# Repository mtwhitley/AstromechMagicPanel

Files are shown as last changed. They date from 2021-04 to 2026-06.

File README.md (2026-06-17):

# Astromech Magic Panel (AMP)

This project enables the building of LED Magic Panels for Astromech (R2-D2) droids. For more information on building your own droid, visit [Astromech.net](https://www.astromech.net)

## About
This version cycles through 8 predefined color pallets at 30 second intervals. The brightness pulses. The colors, intervals, sequences, speed, and density are all configurable. AMP requires 5v.

The default color sequence is:

 - Red, *\<Off\>*
 - Red with hints of Blue
 - Blue, *\<Off\>*
 - Red with hints of White
 - White, *\<Off\>* 
 - Blue with hints of White
 - Blue, *\<Off\>*
 - Rainbow, *\<Off\>*

The build is pretty straightforward but if you have any questions, send me a message in the [Astromech forums](https://astromech.net/forums/member.php?46338-umlungu). I can also be found on [Instagram](https://www.instagram.com/mw.labs/).

## Videos

Click each of the images below to view a video on Youtube of the animation.

Rainbow Animation

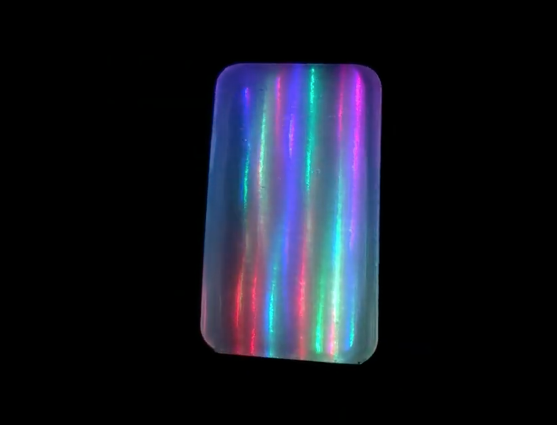
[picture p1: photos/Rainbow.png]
[](https://www.youtube.com/watch?v=29eVVwuxKLU)

Red and Blue Animations

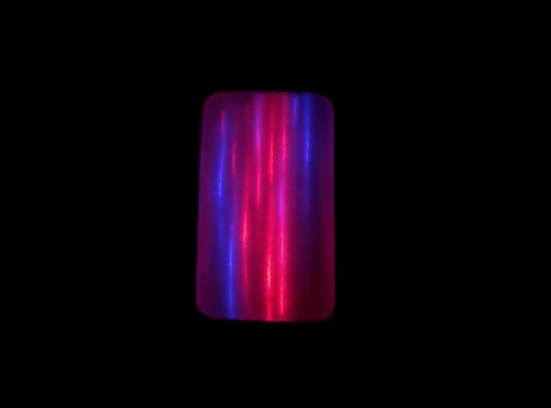
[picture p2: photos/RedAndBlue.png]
[](https://www.youtube.com/watch?v=H4pSufZo-co)

Horizontal & Vertical Lenses Compared

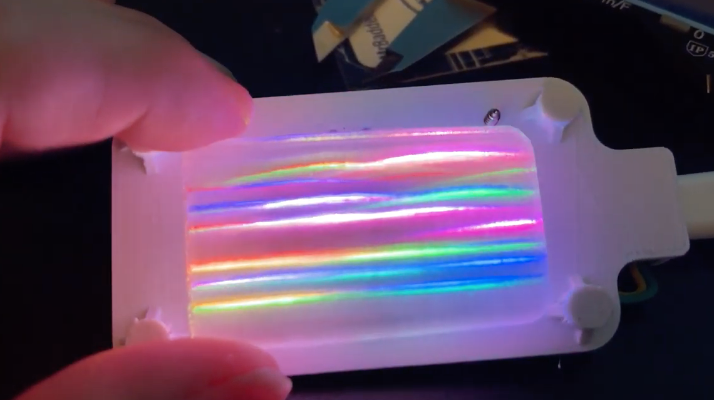
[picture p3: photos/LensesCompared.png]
[](https://www.youtube.com/watch?v=DCI3bl-R6VM)

## Getting Started

To build the Astromech Magic Panel (AMP) you will need the following hardware:

 - 1 x [Adafruit QT Py (SAMD21)](https://www.adafruit.com/product/4600)
 - 2 x [Adafruit DotStar 8x8 Grid](https://www.adafruit.com/product/3444) or [SparkFun LuMini LED Matrix - 8x8](https://www.sparkfun.com/products/15047) The Adafruit Matrix is more densely packed but the Sparkfun Matrix is easier to solder
 - 8 x M2, 6mm screws (Adafruit) or 8 x M3, 6mm screws (Sparkfun)
 - 8 x F/F jumper wires (Adafruit) or 4 x F/F jumper wires (Sparkfun)
 - USB Type-C Cable supporting both Data and Power 
 - Soldering Iron and Solder
 - The [Arduino IDE](https://www.arduino.cc/en/software)
 - The ability to print the included mounting brackets

Here are the components prior to assembly

**Sparkfun LuMini**

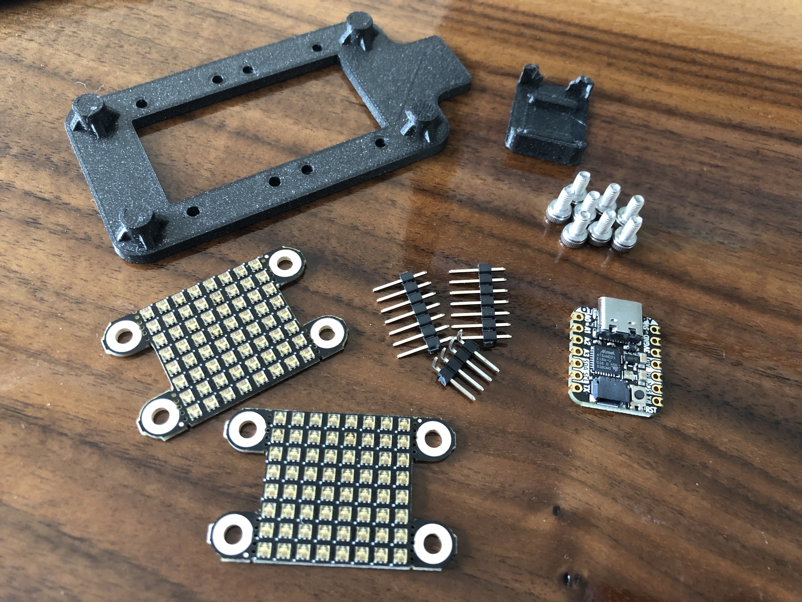
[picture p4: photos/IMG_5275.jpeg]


**Adafruit Dotstar**

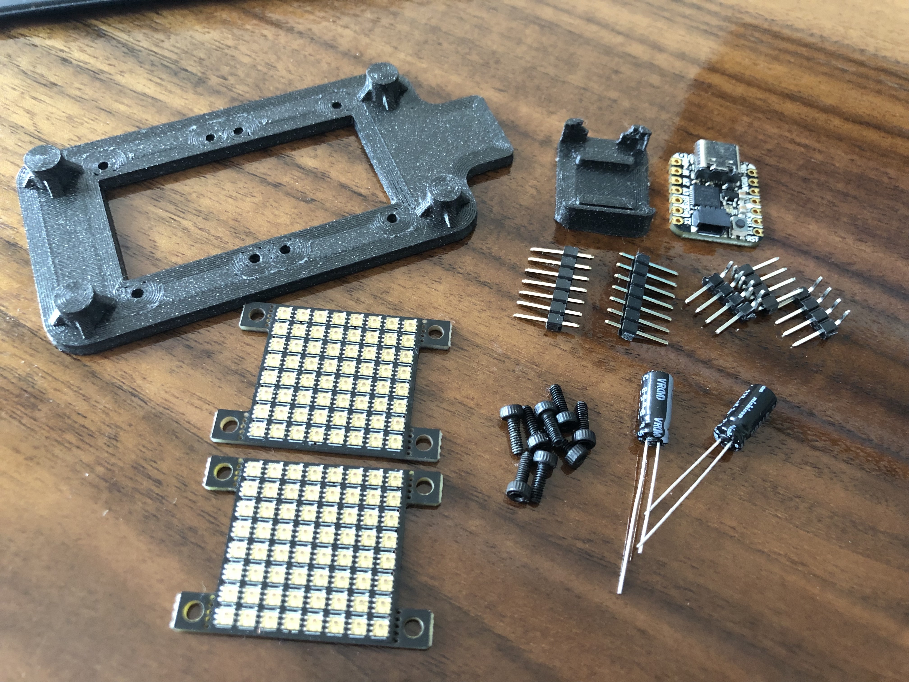
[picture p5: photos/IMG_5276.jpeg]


**Note:** You will also need a semi-transparent Magic Panel. If 3D printing this panel I recommend printing the panel *vertically* using a clear PETG filament. I used 6 perimeters/shells with 10% gyroid infill. Fewer perimeters and less infill will result in poorer LED diffusion. I highly recommend using [Michael Baddeley's](https://www.patreon.com/mrbaddeley/overview) excellent 3D printable models.

### Step 1: Solder 
First, solder the straight header pins to the Adafruit QT Py facing up.

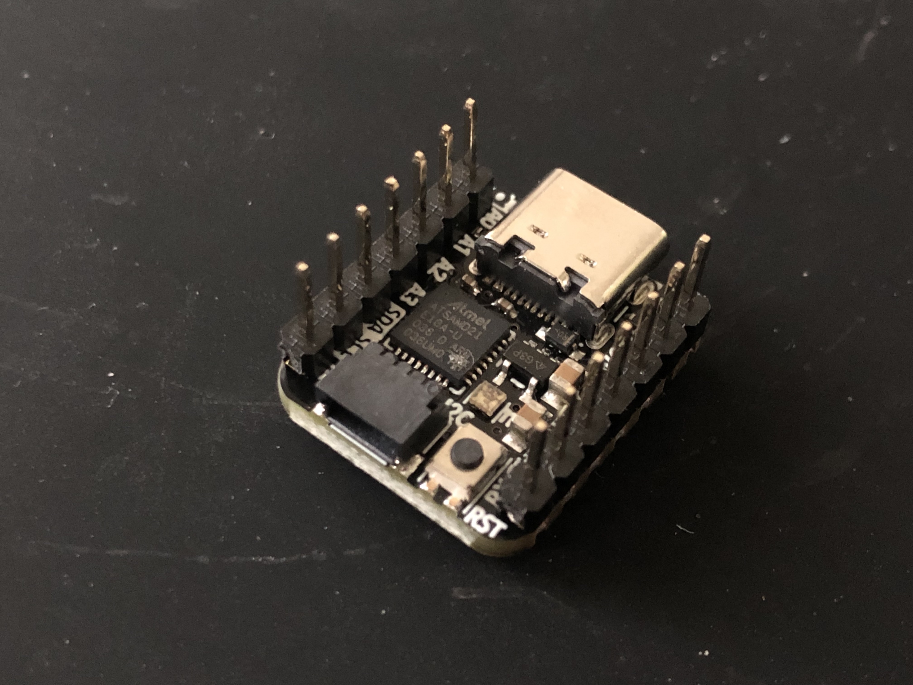
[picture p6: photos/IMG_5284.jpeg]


Next, solder two wires to the power pads on the opposite side of the QT Py.

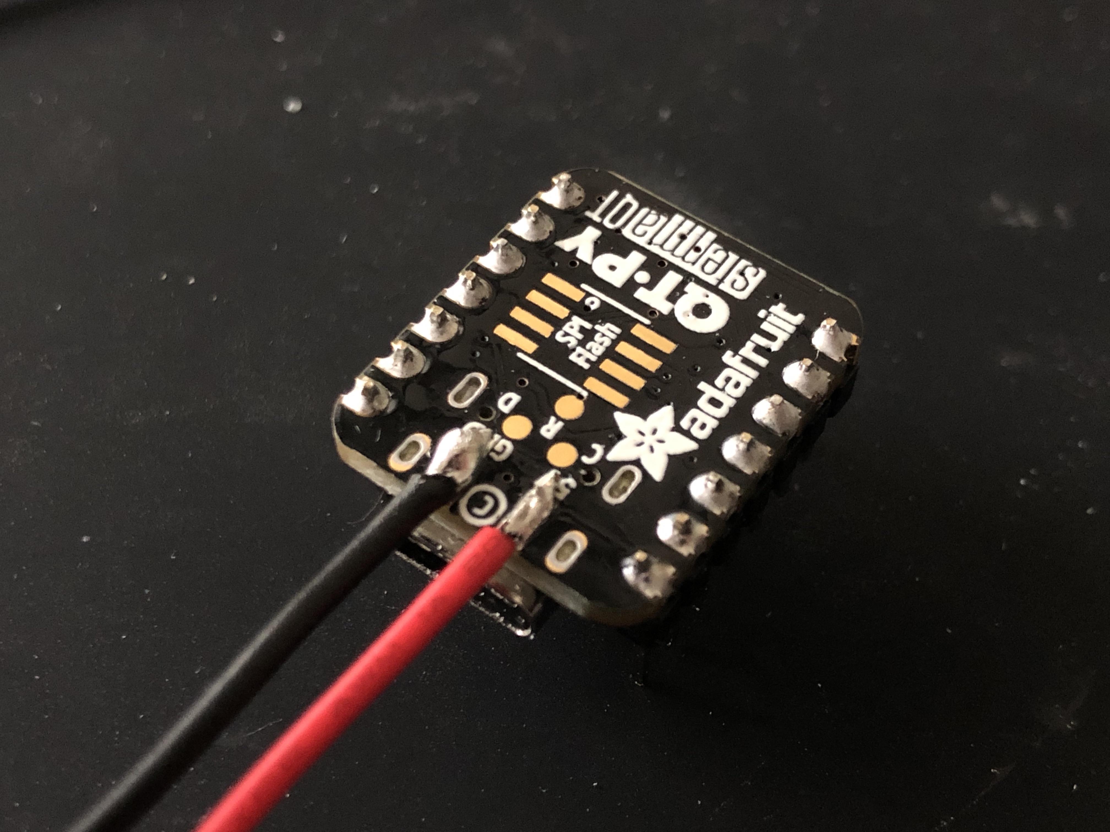
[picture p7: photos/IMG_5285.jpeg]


***Sparkfun Instructions***

Next, solder the 5V, CO-CI, DO-DI, and GND pads together on a flat surface. Also place a bit of solder on the remaining 5V, CI, DI, and GND pads on the top board.

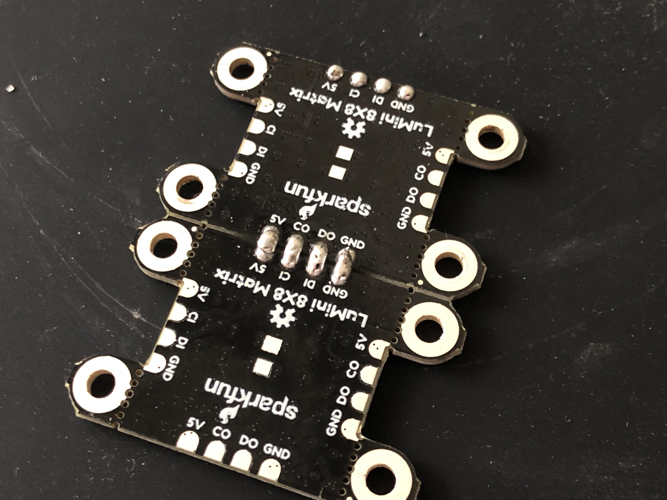
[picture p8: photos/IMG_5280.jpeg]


Next, spread the pins of the right angle headers apart slightly and solder them to the 5V, CI, DI, and GND pads on the top board.

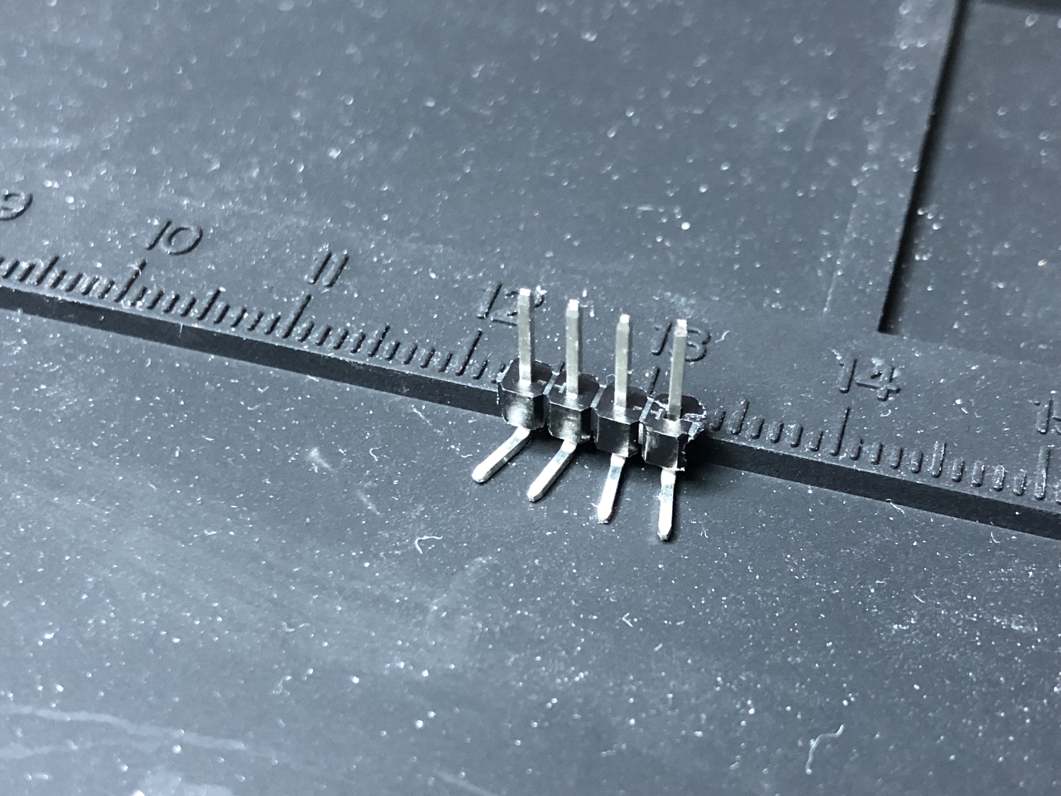
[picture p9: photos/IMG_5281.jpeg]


***Adafruit Instructions***

Next, solder the capacitors supplied with the matrices to the boards. Be sure to solder the + and - capacitor leads to the corresponding pads on the board. Once soldered trim the leads. Also place a bit of solder on the CIN, DIN, GND, and +5V pads. Do the same for the +5V, GND, DOUT, and COUT pads on one of the boards.

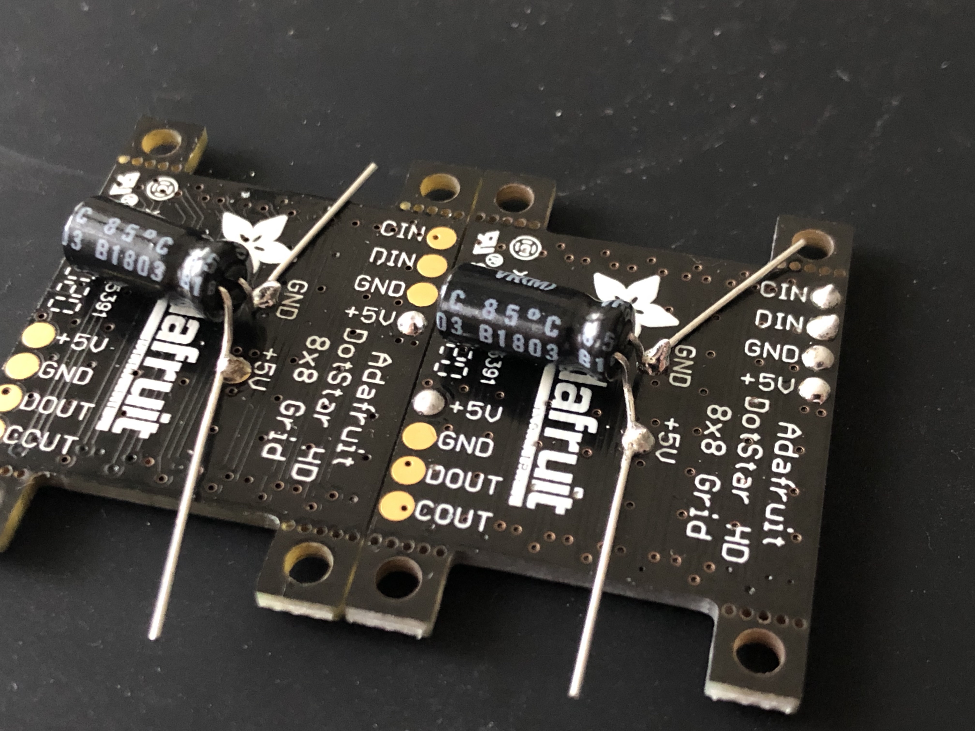
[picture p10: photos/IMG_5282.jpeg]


Next, solder the right angle headers to the pads prepared in the step above. Note that with the Adafruit board the right angle headers do not need to be spread apart.

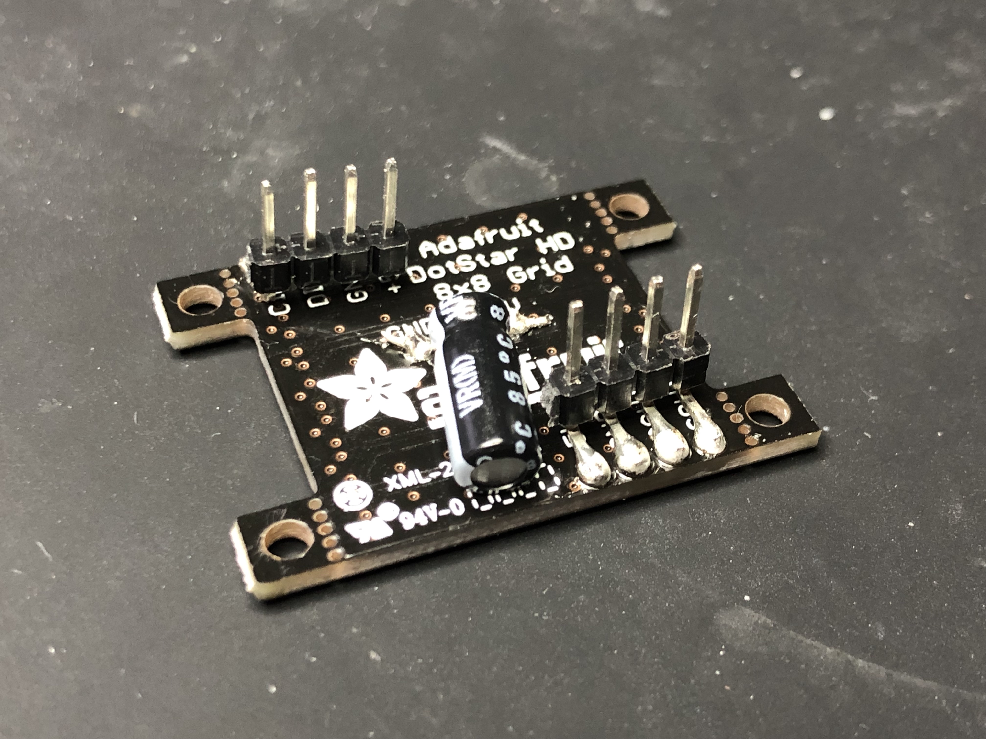
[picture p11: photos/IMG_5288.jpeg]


### Step 2: Program
Using a USB C cable, a computer, and the [Arduino IDE](https://www.arduino.cc/en/software), connect the QT Py microcontroller and upload the *AstromechMagicPanel.ino* sketch found in the *src* directory.

### Step 3: Print
3D print the QT Py and Base mounting brackets found in the models folder. Only print the base model corresponding to the LED matrix you are using.

Print the Magic Panel *vertically* (standing on the shorter side) using clear PETG filament. I used 6 perimeters/shells with 10% gyroid infill. Fewer perimeters and less infill will result in poorer LED diffusion. I recommend using "Panel 7" model from [Michael Baddeley's](https://www.patreon.com/mrbaddeley/overview) project.  The light is diffused perpendicular to the print layer direction.

### Step 4: Assemble
Next, use CA glue to attach the QT Py bracket to the base.

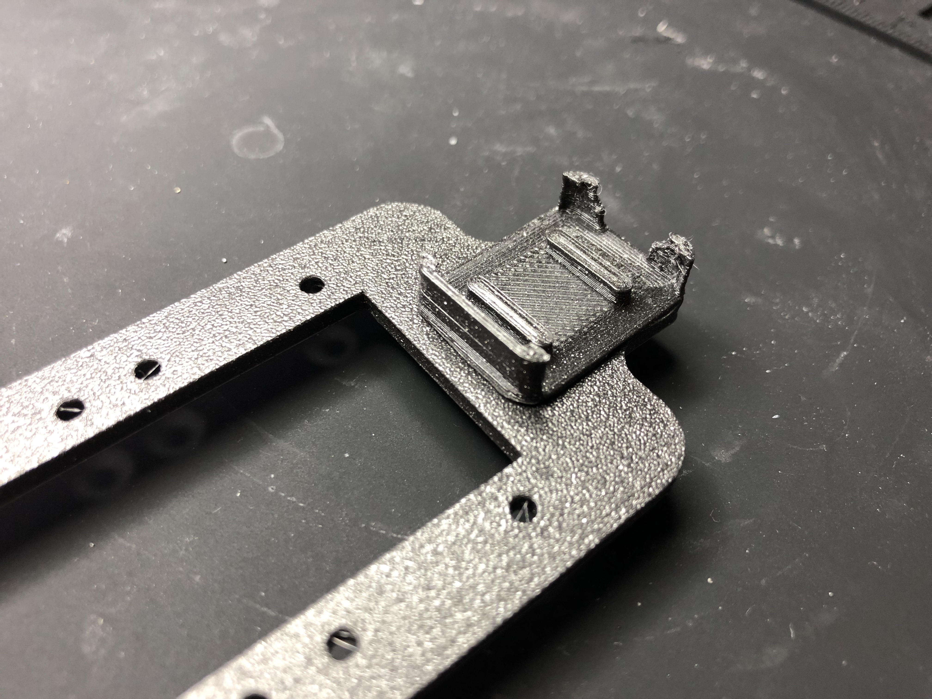
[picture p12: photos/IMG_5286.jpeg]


Next, screw the LED panels into the bracket.

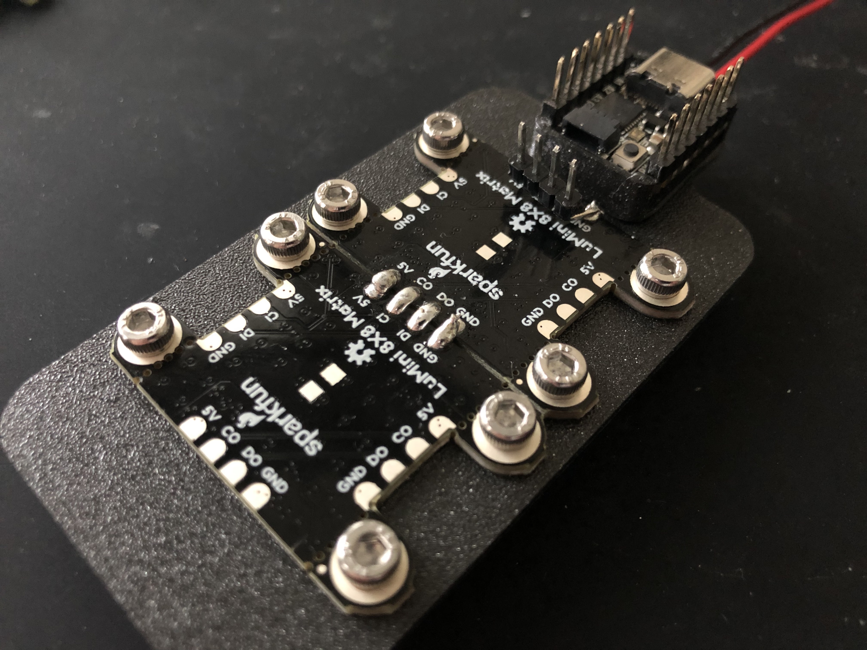
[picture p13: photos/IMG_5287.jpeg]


Then connect the QT Py to the LED panels using the female jumper wires. If using the Sparkfun Lumini, connect CI to pin 0 and DI to pin 1. If using Adafruit Dotstar, connect CIN to pin 0 and DIN to pin 1. Don't forget to connect the 5V and GND pins as well. 

**Assembled Sparkfun LuMini AMP**

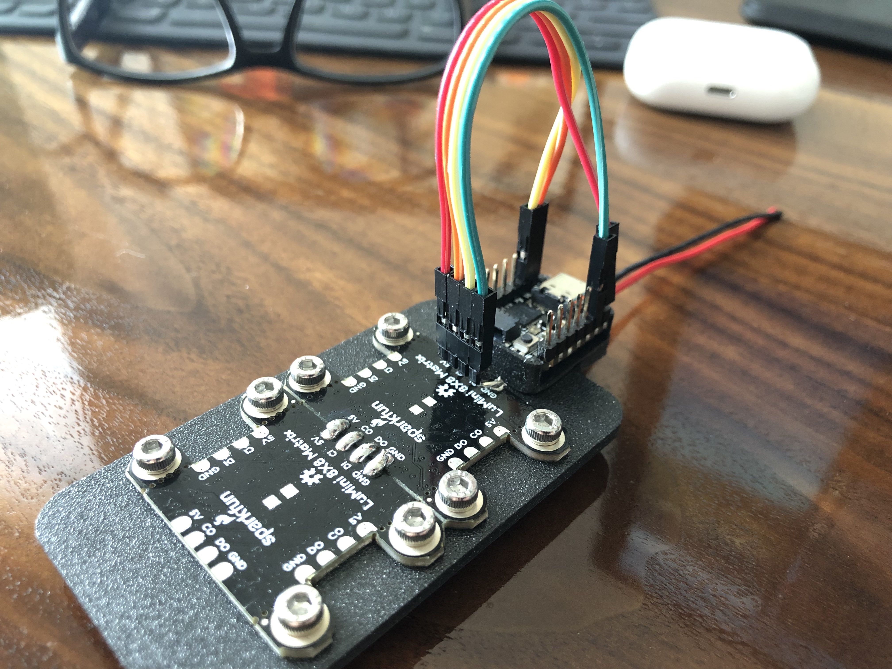
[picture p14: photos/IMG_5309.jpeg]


**Assembled Adafruit Dotstar AMP**

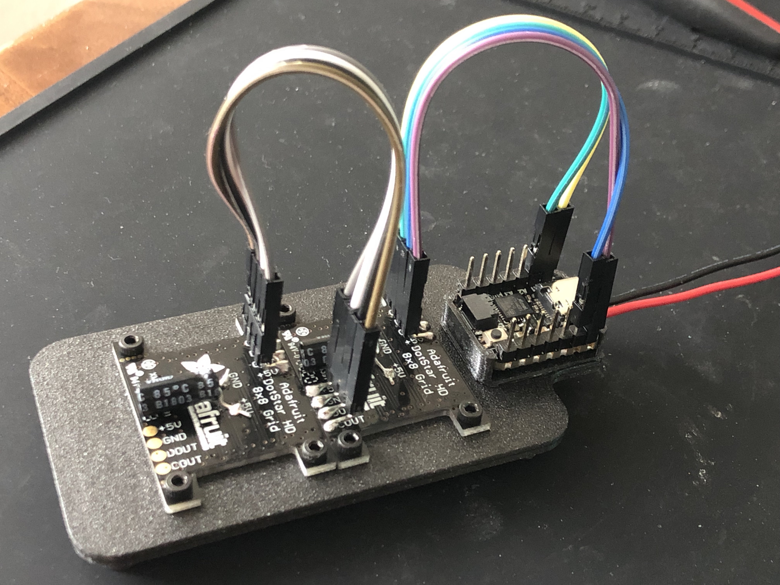
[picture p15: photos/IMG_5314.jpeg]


Once assembled, AMP can be installed into the dome directly over the semi-transparent Magic Panel and connected to a 5v power supply.

## More Help
For additional assistance please contact Michael Whitley (umlungu) on the Astromech.net forums.

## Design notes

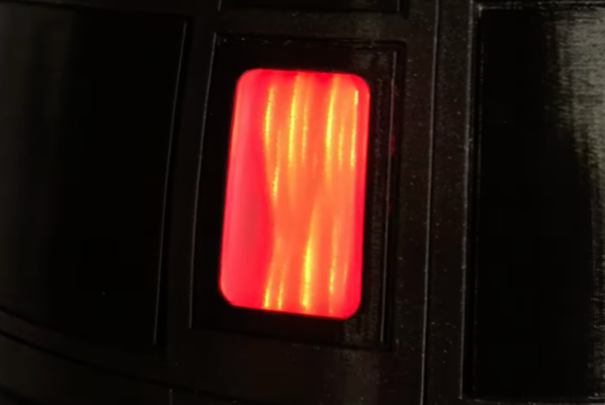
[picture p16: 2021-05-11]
photos/Red.png

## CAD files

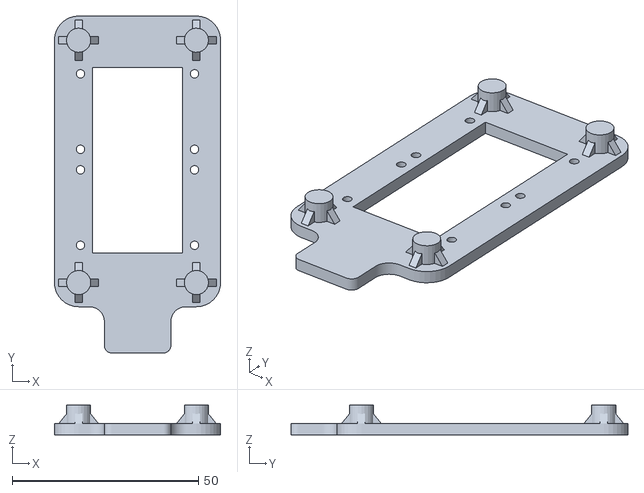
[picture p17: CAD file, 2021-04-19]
models/AstromechMagicPanel_Base-Adafruit.stl
44.6 x 90.4 x 8.00

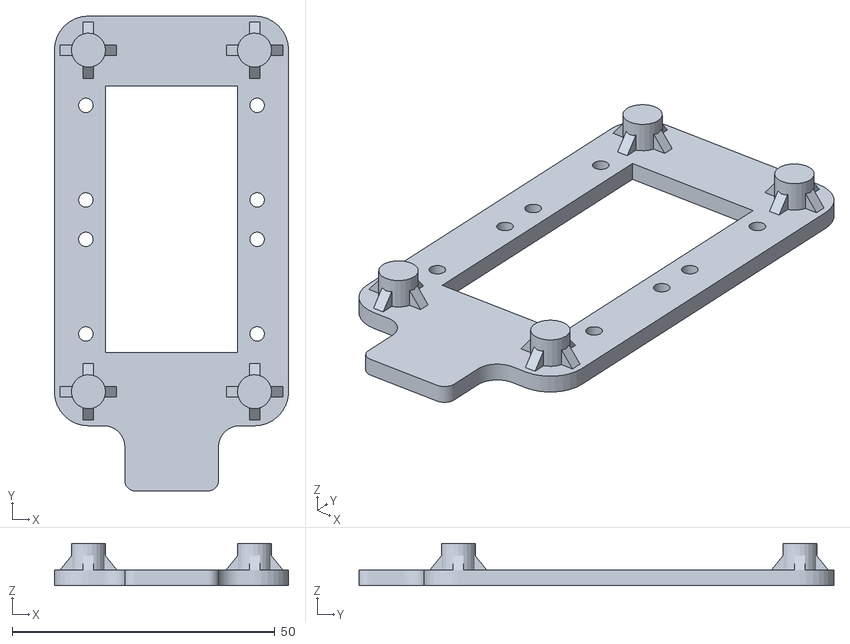
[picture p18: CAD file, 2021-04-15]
models/AstromechMagicPanel_Base-Sparkfun.stl
44.6 x 90.4 x 8.00

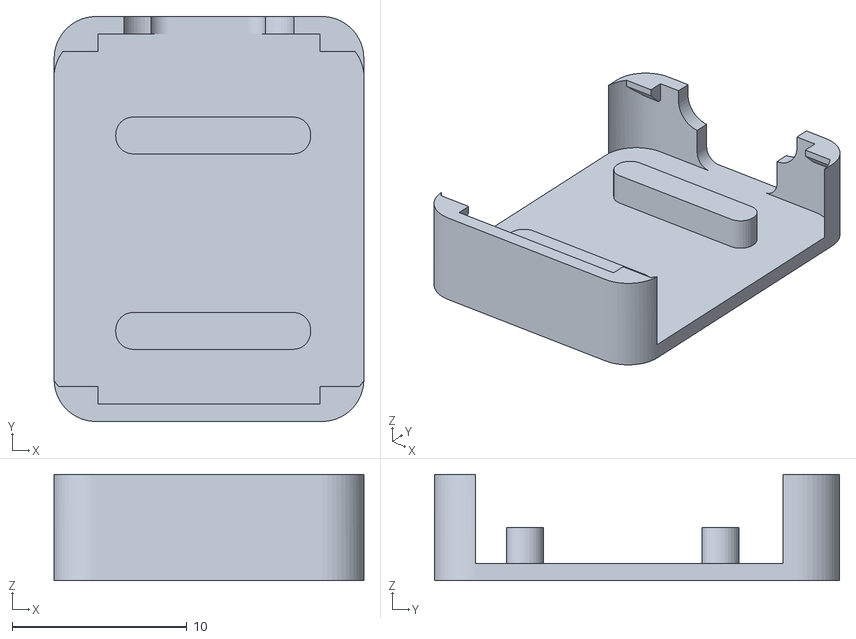
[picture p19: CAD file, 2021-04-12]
models/AstromechMagicPanel_QTPy.stl
17.7 x 23.2 x 6.10

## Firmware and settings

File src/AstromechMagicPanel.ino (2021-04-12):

#include "FastLED.h"

// =======================================================================================
//  Astromech Magic Panel (AMP)
// =======================================================================================
//                                 
// This code animates the Magic Panel for Astromech droids. When combined with a semi-
// transparent panel and LEDs it produces a striking effect. This code is based on 
// FastLED's TwinkleFox example http://fastled.io
//
// Homepage: https://github.com/mtwhitley/AstromechMagicPanel
// 
// Authors: Michael Whitley (astromech.net - umlungu), Mark Kriegsman (FastLED)
//
// Required Library: 
//   FastLED
//
// Setup: Use with 2 x APA102 20/20 8x8 matrix panels from Adafruit or Sparkfun. 
// I recommend using an Adafruit QT Py to drive the LEDs, but any 
// microcontroller 16MHz or faster will likely work. If using a different board
// be sure to adjust the Data and Clock pins accordingly.
//
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
#define DATA_PIN 1          // Adafruit QT Py
#define CLK_PIN  0          // Adafruit QT Py
#define LED_TYPE    APA102  // APA102 20/20 8x8 matrix panels 
#define COLOR_ORDER BGR     // APA102 20/20 8x8 matrix panels 
#define NUM_LEDS    128     // 2 x APA102 20/20 8x8 matrix panels 
#define BRIGHTNESS  25      // The LED panels can get HOT so don't go above 25-30 max

// Overall twinkle speed.
// 0 (VERY slow) to 8 (VERY fast).  
// Default is 4.
int twinkle_speed=4;

// Overall twinkle density.
// 0 (NONE lit) to 8 (ALL lit at once).  
// Default is 2.
int twinkle_density=2;

// How often to change color palettes.
#define SECONDS_PER_PALETTE  30

// =======================================================================================
//  Color Pallete Definitions - Use "CRGB::Gray" for white to keep the brightness uniform
// =======================================================================================

const TProgmemRGBPalette16 White_p FL_PROGMEM =
{  CRGB::Gray,  CRGB::Gray,  CRGB::Gray,  CRGB::Gray,
   CRGB::Gray,  CRGB::Gray,  CRGB::Gray,  CRGB::Gray,
   CRGB::Gray,  CRGB::Gray,  CRGB::Gray,  CRGB::Gray,
   CRGB::Gray,  CRGB::Gray,  CRGB::Gray,  CRGB::Gray};

const TProgmemRGBPalette16 Red_p FL_PROGMEM =
{  CRGB::Red,  CRGB::Red,  CRGB::Red,  CRGB::Red,
   CRGB::Red,  CRGB::Red,  CRGB::Red,  CRGB::Red,
   CRGB::Red,  CRGB::Red,  CRGB::Red,  CRGB::Red,
   CRGB::Red,  CRGB::Red,  CRGB::Red,  CRGB::Red};

const TProgmemRGBPalette16 Blue_p FL_PROGMEM =
{  CRGB::Blue,  CRGB::Blue,  CRGB::Blue,  CRGB::Blue,
   CRGB::Blue,  CRGB::Blue,  CRGB::Blue,  CRGB::Blue,
   CRGB::Blue,  CRGB::Blue,  CRGB::Blue,  CRGB::Blue,
   CRGB::Blue,  CRGB::Blue,  CRGB::Blue,  CRGB::Blue};

const TProgmemRGBPalette16 Black_p FL_PROGMEM =
{  CRGB::Black,  CRGB::Black,  CRGB::Black,  CRGB::Black,
   CRGB::Black,  CRGB::Black,  CRGB::Black,  CRGB::Black,
   CRGB::Black,  CRGB::Black,  CRGB::Black,  CRGB::Black,
   CRGB::Black,  CRGB::Black,  CRGB::Black,  CRGB::Black};

const TProgmemRGBPalette16 RedWhite_p FL_PROGMEM =
{  CRGB::Red,  CRGB::Red,  CRGB::Red,  CRGB::Red, 
   CRGB::Red, CRGB::Gray, CRGB::Red, CRGB::Gray,
   CRGB::Red,  CRGB::Red,  CRGB::Red,  CRGB::Red, 
   CRGB::Gray, CRGB::Red, CRGB::Gray, CRGB::Red };

const TProgmemRGBPalette16 RedBlue_p FL_PROGMEM =
{  CRGB::Red,  CRGB::Red,  CRGB::Red,  CRGB::Red, 
   CRGB::Blue, CRGB::Blue, CRGB::Blue, CRGB::Blue,
   CRGB::Red,  CRGB::Red,  CRGB::Red,  CRGB::Red, 
   CRGB::Red, CRGB::Red, CRGB::Blue, CRGB::Blue };

const TProgmemRGBPalette16 BlueWhite_p FL_PROGMEM =
{  CRGB::Blue, CRGB::Blue, CRGB::Blue, CRGB::Blue, 
   CRGB::Blue, CRGB::Blue, CRGB::Blue, CRGB::Blue, 
   CRGB::Blue, CRGB::Blue, CRGB::Blue, CRGB::Blue, 
   CRGB::Blue, CRGB::Blue, CRGB::Blue, CRGB::Gray };

// =======================================================================================
//  Color Pallete Order - Use "&Black_p" for OFF
// =======================================================================================

const TProgmemRGBPalette16* ActivePaletteList[] = {
   &Red_p,
   &Red_p,
   &Black_p,
   &RedBlue_p,
   &Blue_p,
   &Black_p,
   &RedWhite_p,
   &White_p,
   &White_p,
   &Black_p,
   &BlueWhite_p,
   &Blue_p,
   &Blue_p,
   &Black_p,
   &RainbowColors_p,
   &RainbowColors_p,
   &Black_p,
};

// =======================================================================================
//  Main Program - Shouldn't need to edit below
// =======================================================================================

#define AUTO_SELECT_BACKGROUND_COLOR 0
#define COOL_LIKE_INCANDESCENT 0
CRGB gBackgroundColor = CRGB::Black;
CRGBArray<NUM_LEDS> leds;
CRGBPalette16 gCurrentPalette;
CRGBPalette16 gTargetPalette;

void setup() {
  delay( 3000 );
  FastLED.addLeds<LED_TYPE,DATA_PIN,CLK_PIN,COLOR_ORDER>(leds, NUM_LEDS)
    .setCorrection(TypicalLEDStrip);
  FastLED.setBrightness(BRIGHTNESS);

  chooseNextColorPalette(gTargetPalette);
}

void loop() {
  EVERY_N_SECONDS( SECONDS_PER_PALETTE ) { 
    chooseNextColorPalette( gTargetPalette ); 
  }
  
  EVERY_N_MILLISECONDS( 10 ) {
    nblendPaletteTowardPalette( gCurrentPalette, gTargetPalette, 12);
  }

  drawTwinkles( leds);
  
  FastLED.show();
}

void drawTwinkles( CRGBSet& L) {
  uint16_t PRNG16 = 11337;
  
  uint32_t clock32 = millis();

  CRGB bg;
  if( (AUTO_SELECT_BACKGROUND_COLOR == 1) &&
      (gCurrentPalette[0] == gCurrentPalette[1] )) {
    bg = gCurrentPalette[0];
    uint8_t bglight = bg.getAverageLight();
    if( bglight > 64) {
      bg.nscale8_video( 16);
    } else if( bglight > 16) {
      bg.nscale8_video( 64);
    } else {
      bg.nscale8_video( 86);
    }
  } else {
    bg = gBackgroundColor;
  }

  uint8_t backgroundBrightness = bg.getAverageLight();
  
  for( CRGB& pixel: L) {
    PRNG16 = (uint16_t)(PRNG16 * 2053) + 1384;
    uint16_t myclockoffset16= PRNG16;
    PRNG16 = (uint16_t)(PRNG16 * 2053) + 1384;
    uint8_t myspeedmultiplierQ5_3 =  ((((PRNG16 & 0xFF)>>4) + (PRNG16 & 0x0F)) & 0x0F) + 0x08;
    uint32_t myclock30 = (uint32_t)((clock32 * myspeedmultiplierQ5_3) >> 3) + myclockoffset16;
    uint8_t  myunique8 = PRNG16 >> 8;

    CRGB c = computeOneTwinkle( myclock30, myunique8);

    uint8_t cbright = c.getAverageLight();
    int16_t deltabright = cbright - backgroundBrightness;
    if( deltabright >= 32 || (!bg)) {
      pixel = c;
    } else if( deltabright > 0 ) {
      pixel = blend( bg, c, deltabright * 8);
    } else { 
      pixel = bg;
    }
  }
}

CRGB computeOneTwinkle( uint32_t ms, uint8_t salt) {
  uint16_t ticks = ms >> (8-twinkle_speed);
  uint8_t fastcycle8 = ticks;
  uint16_t slowcycle16 = (ticks >> 8) + salt;
  slowcycle16 += sin8( slowcycle16);
  slowcycle16 =  (slowcycle16 * 2053) + 1384;
  uint8_t slowcycle8 = (slowcycle16 & 0xFF) + (slowcycle16 >> 8);
  
  uint8_t bright = 0;
  if( ((slowcycle8 & 0x0E)/2) < twinkle_density) {
    bright = attackDecayWave8( fastcycle8);
  }

  uint8_t hue = slowcycle8 - salt;
  CRGB c;
  if( bright > 0) {
    c = ColorFromPalette( gCurrentPalette, hue, bright, NOBLEND);
    if( COOL_LIKE_INCANDESCENT == 1 ) {
      coolLikeIncandescent( c, fastcycle8);
    }
  } else {
    c = CRGB::Black;
  }
  return c;
}

uint8_t attackDecayWave8( uint8_t i) {
  if( i < 86) {
    return i * 3;
  } else {
    i -= 86;
    return 255 - (i + (i/2));
  }
}

void coolLikeIncandescent( CRGB& c, uint8_t phase) {
  if( phase < 128) return;

  uint8_t cooling = (phase - 128) >> 4;
  c.g = qsub8( c.g, cooling);
  c.b = qsub8( c.b, cooling * 2);
}

void chooseNextColorPalette( CRGBPalette16& pal) {
  const uint8_t numberOfPalettes = sizeof(ActivePaletteList) / sizeof(ActivePaletteList[0]);
  static uint8_t whichPalette = -1; 
  whichPalette = addmod8( whichPalette, 1, numberOfPalettes);

  pal = *(ActivePaletteList[whichPalette]);
}

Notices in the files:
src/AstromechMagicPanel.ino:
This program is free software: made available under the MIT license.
